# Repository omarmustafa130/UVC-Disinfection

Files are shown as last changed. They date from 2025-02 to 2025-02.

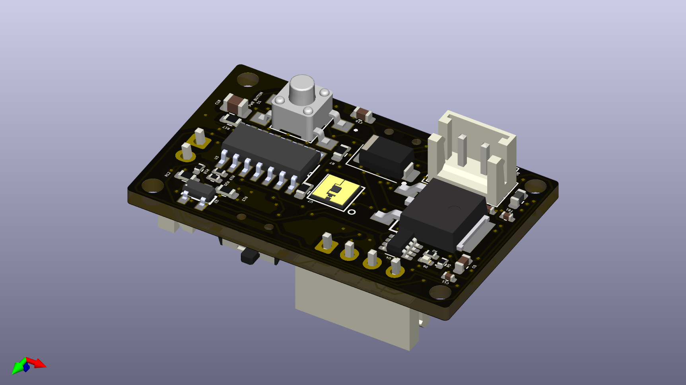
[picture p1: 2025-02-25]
Screenshots/Bottom3D_2.png

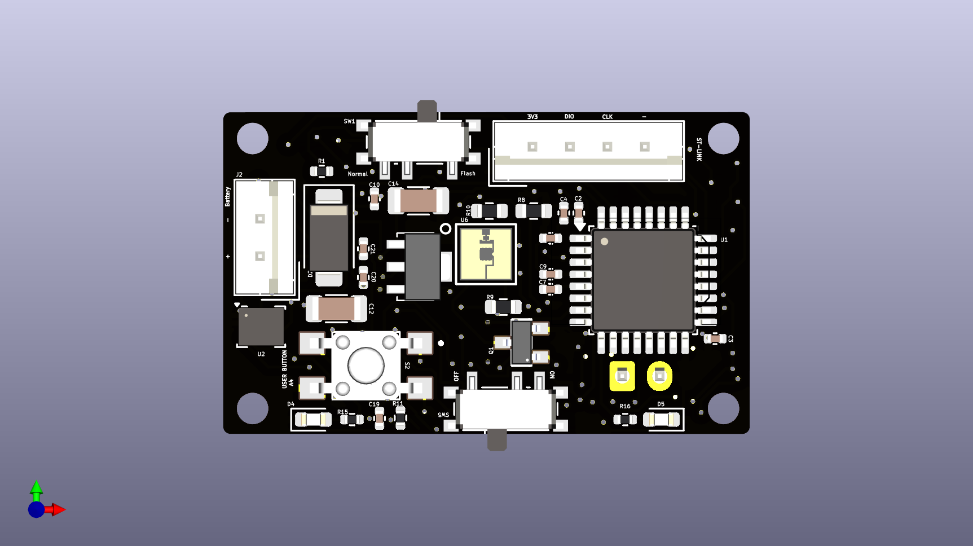
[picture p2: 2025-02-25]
Screenshots/Top3D_1.png

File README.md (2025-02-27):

# Hardware & PCB -- Scroll down for software part
The board is very, very compact, at just 21mm x 35mm, designed as a double-layer PCB, and integrates a smart power control system alongside motion-based UVC LED activation, and is able to last +30 days on battery.

The board features:
1- MCU: STM32L031K6T – a low-power Cortex-M0+ MCU to handle control logic efficiently.

2- Motion Sensing: LSM6DS3 – a 3D accelerometer & gyroscope determines orientation to activate the correct UVC LED.

3- UVC LEDs: 2x 254nm LEDs (23mW, 150mA) – ensure effective disinfection, switching every 60 minutes for 90 seconds based on orientation.

4- Power Management:
- L7BM06CDT (6V regulator)
- L78L33ACUTR (3.3V regulator) for the MCU
- MCP73831-2-MC (Li-ion charging IC) for battery management

5- User Interface & Control:
- Status LEDs (2x) & Power LED (1x) for feedback.
- A user button for additional interaction.
- Power Button using D Flip-Flop (74HC74) – holds power after a 5-second press, controlled via an RC delay circuit.
Instead of an always-on MCU (to save the battery), the device remains completely powered off until the user presses the power button for 5 seconds.
Uses a D flip-flop latch circuit with an RC network to ensure accidental presses don’t turn it on.
- ON/OFF Switch for direct power control when needed.
- 4-pin JST connector for ST-LINK interface
- Two 2-pin JST connector for the batteries and their charger

# Software 
# **STM32 UVC LED Control with Low Power Mode**

## **Overview**

This project controls **UVC LEDs** based on the device's **orientation**, using an **LSM6DS33 accelerometer**. It follows a power-efficient cycle:

1. **Waits 30 seconds** before activating.
2. **Blinks an indicator LED for 5 seconds**.
3. **Determines the orientation** of the device.
4. **Activates the appropriate UVC LED** for **90 seconds** while the indicator LED blinks.
5. **Turns OFF all LEDs** after operation.
6. **Enters deep sleep mode (STOP mode) for 1 hour** to conserve power.

The system **wakes up automatically after 1 hour** and repeats the cycle.

---

## **Hardware Requirements**

To test this code, you need:

- **STM32 (e.g., STM32F103RB Nucleo or similar)**
- **LSM6DS33 Accelerometer (I2C)**
- **UVC LEDs** (connected to GPIOA)
- **Indicator LEDs**
- **Power supply** (battery or USB)

---

## **Pin Configuration**

| **Component** | **GPIO Pin** | **Port** |
| --- | --- | --- |
| **Top UVC LED** | `GPIO_PIN_0` | `GPIOA`  |
| **Bottom UVC LED** | `GPIO_PIN_1` | `GPIOA`  |
| **Top Indicator LED** | `GPIO_PIN_3` | `GPIOA`  |
| **Bottom Indicator LED** | `GPIO_PIN_7` | `GPIOA`  |
| **I2C SDA** | `GPIO_PIN_9` | `GPIOB`  |
| **I2C SCL** | `GPIO_PIN_8` | `GPIOB`  |

---

## **Project Structure**

```
/STM32_UVC_LowPower/
│── Core/
│   ├── Inc/
│   │   ├── main.h
│   │   ├── LSM6DS33.h
│   ├── Src/
│   │   ├── main.c
│   │   ├── LSM6DS33.c
│── README.md
```

---

## **How It Works**

### **1- Initialization**

- **STM32 peripherals** (GPIO, I2C, System Clock) are initialized.
- **LSM6DS33 accelerometer** is configured.

### **2- LED Activation Sequence**

- **Waits 30 seconds** after boot.
- **Blinks indicator LED** for **5 seconds**.
- **Reads orientation** from **LSM6DS33**.
- **Turns ON the correct UVC LED** (based on orientation).
- **Blinks indicator LED for 90 seconds** while UVC LED is ON.
- **Turns OFF all LEDs** after the cycle.

### **3- Power Saving Mode**

- **Enters STOP mode (Deep Sleep) for 1 hour.**
- **Disables unused peripherals (GPIO, I2C) before sleep.**
- **Resumes peripherals after waking up.**
- **Restores system clock to normal operation.**
- **Repeats the process indefinitely.**

---

## **How to Test**

### **🔹 Option 1: Flash and Run**

1. **Flash the firmware** using STM32CubeProgrammer or an ST-Link.
2. **Connect serial monitor** to see debug messages (optional).
3. **Observe LED behavior**:
   - Indicator LED blinks for 5 seconds.
   - UVC LED turns ON based on orientation.
   - Indicator LED blinks for 90 seconds while UVC is ON.
   - After LEDs turn OFF, the system **enters low-power mode for 1 hour**.
   - The process repeats.

### **🔹 Option 2: Modify Sleep Duration for Testing**

Since **1-hour sleep is long**, modify `enter_low_power_mode()` for quicker tests:

```c
while ((HAL_GetTick() - tickstart) < 30000)  // 30 seconds instead of 1 hour
```

This allows testing the **wake-up cycle faster**.

---

## **Power Consumption & Optimization**

| **Mode** | **Power Consumption** |
| --- | --- |
| **Active (LEDs ON, CPU running)** | \~20mA |
| **Deep Sleep (STOP Mode, LEDs OFF)** | **\~200-500µA** |
| **Estimated Battery Life (1000mAh battery)** | \~66 Days |

🔹 **Further Power Optimizations:**

- Use **Standby Mode (\~1µA) instead of STOP mode**.
- **Disable more peripherals** (e.g., ADC, UART, timers).
- Use an **RTC wake-up instead of HAL\_GetTick().**

---

## **Troubleshooting**

### **1- STM32 Doesn’t Wake Up**

**Solution: Ensure SysTick timer is active**

- **HAL\_SuspendTick()** prevents unwanted wake-ups.
- **`SCB->SCR |= SCB_SCR_SLEEPDEEP_Msk;`** is required for STOP mode.

### **2- I2C Stops Working After Wake-up**

**Solution: Reset I2C after STOP mode**

```c
__HAL_RCC_I2C1_FORCE_RESET();
HAL_Delay(10);
__HAL_RCC_I2C1_RELEASE_RESET();
MX_I2C1_Init();
LSM6DS33_init();
```

### **3- UVC LED Doesn't Turn ON**

**Solution: Check orientation detection**

- Add debug prints:

```c
printf("Orientation: %d
", orientation);
```

---

## **Additional Resources**

- [STM32 HAL Documentation](https://www.st.com/en/embedded-software/stm32cube-mcu-packages.html)
- [LSM6DS33 Datasheet](https://www.st.com/resource/en/datasheet/lsm6ds33.pdf)
- [Low Power Modes on STM32](https://www.st.com/resource/en/application_note/an4830-lowpower-modes-for-stm32-mcus.pdf)

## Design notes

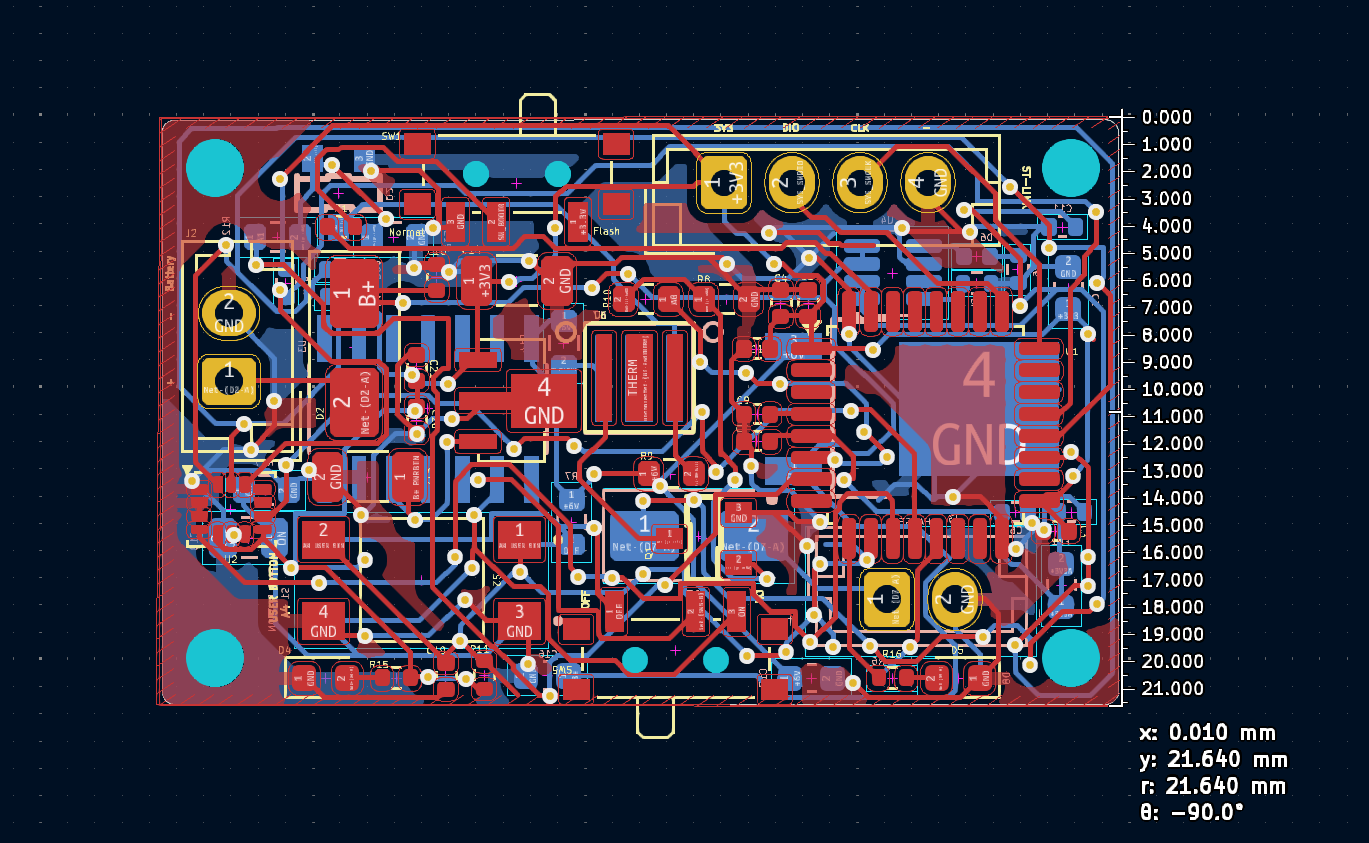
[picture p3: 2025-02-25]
Screenshots/dim2.png

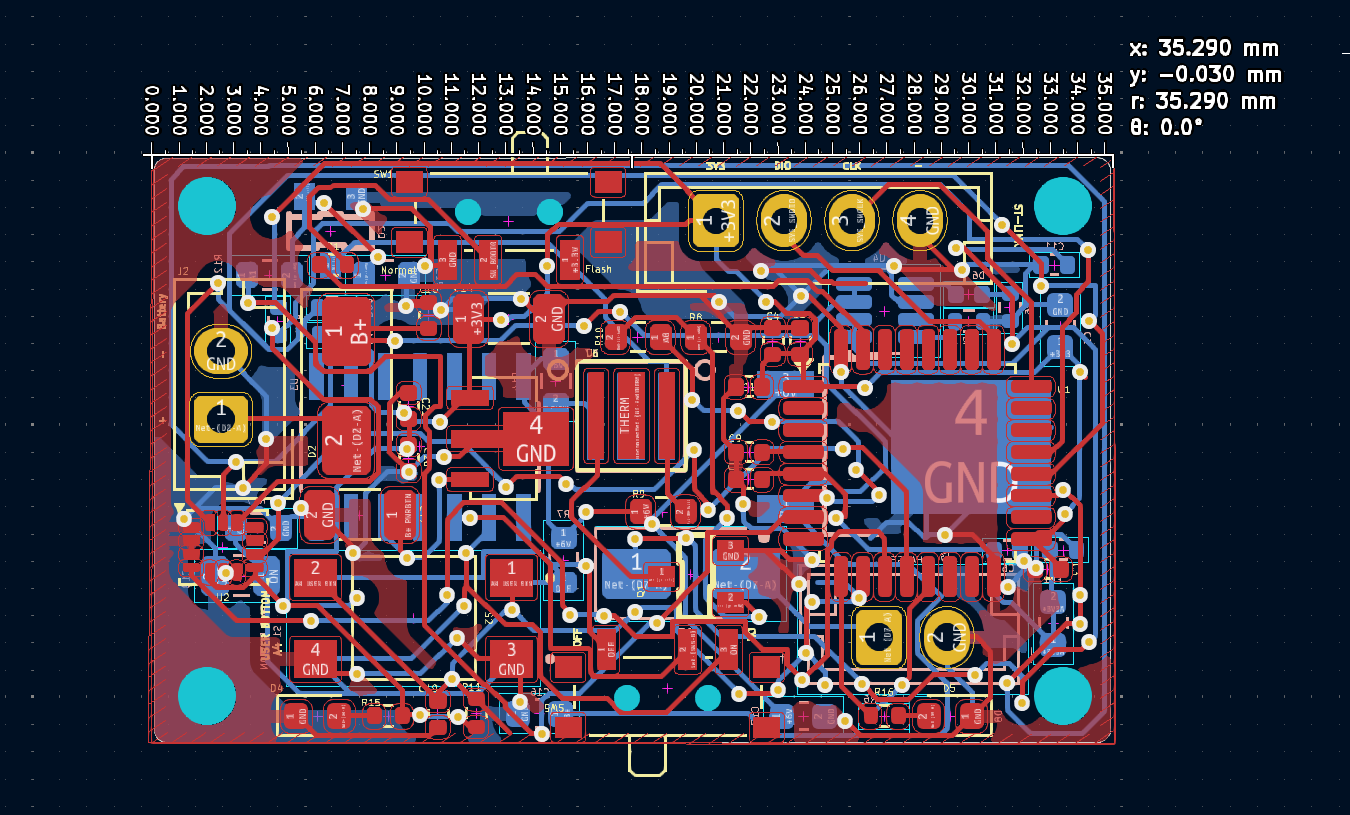
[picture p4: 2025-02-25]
Screenshots/dim1.png

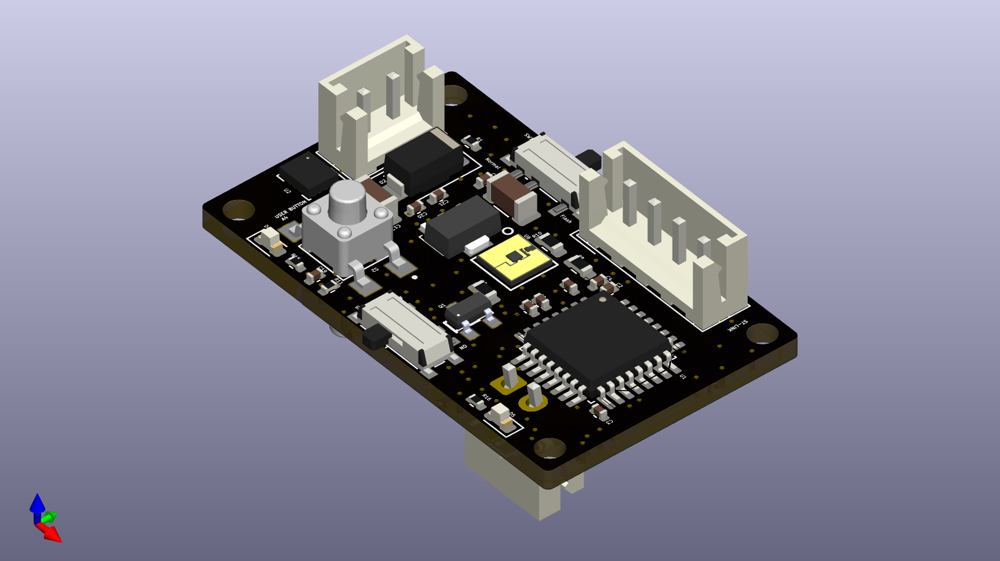
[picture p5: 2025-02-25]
Screenshots/Top3D_3.png

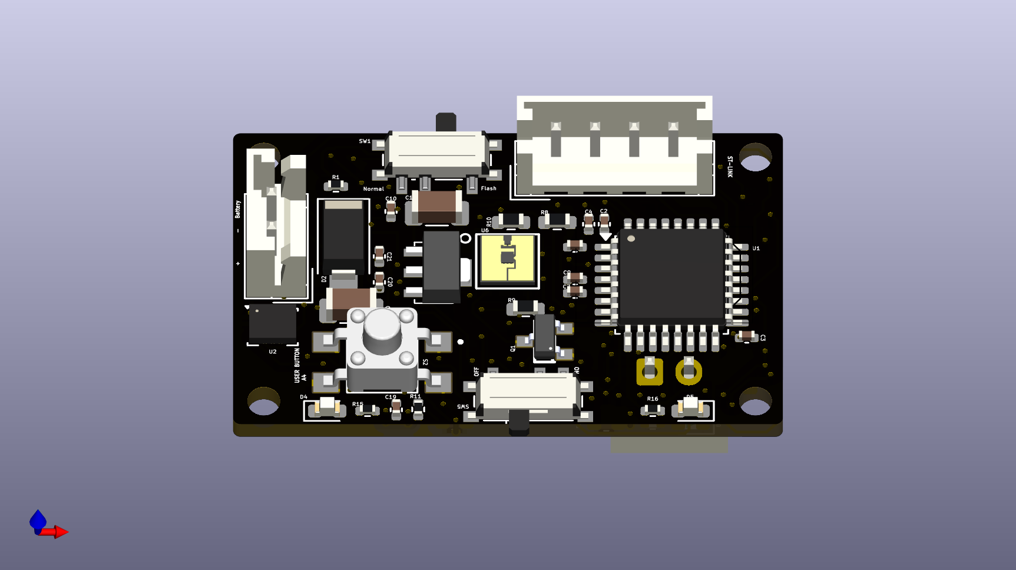
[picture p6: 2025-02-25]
Screenshots/Top3D_2.png

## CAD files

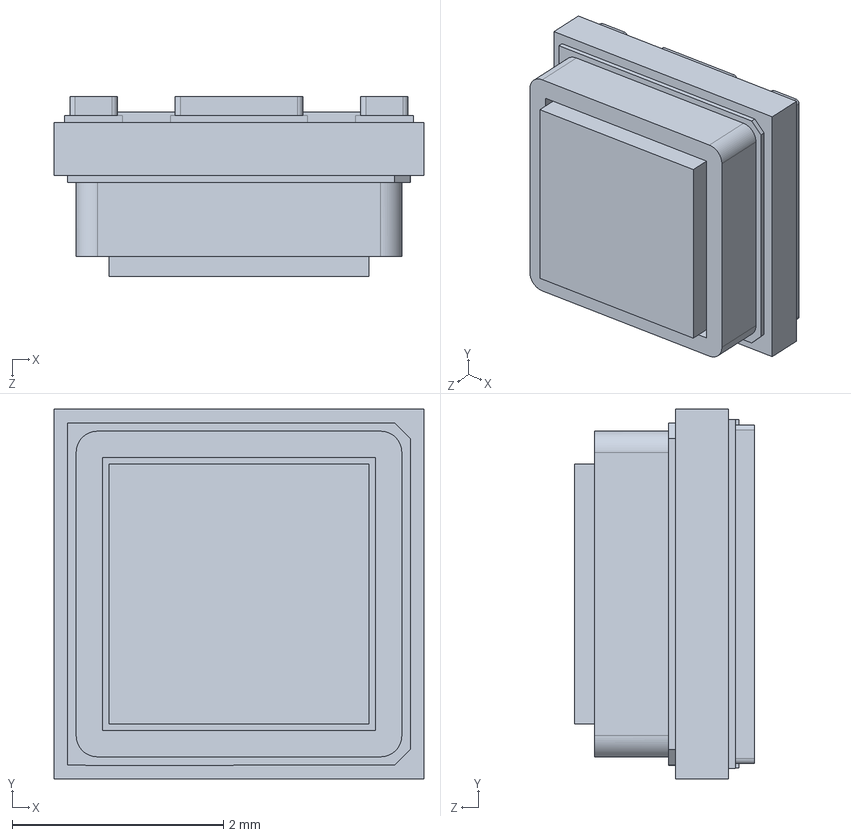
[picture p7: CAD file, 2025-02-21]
Additional symbols, footprints & 3D models/158810696-3-q65113a3141/SU_CULCN1_VC_20210621_geometry.STEP
3.50 x 3.50 x 1.70 mm

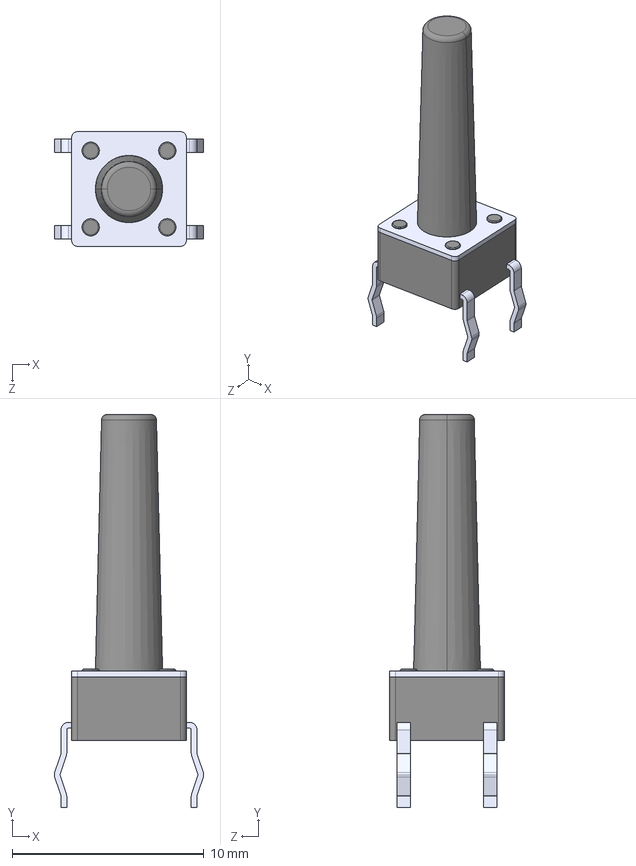
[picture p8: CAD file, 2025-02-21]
Additional symbols, footprints & 3D models/3-1825910-1/3-1825910-1.step
7.80 x 20.5 x 5.99 mm

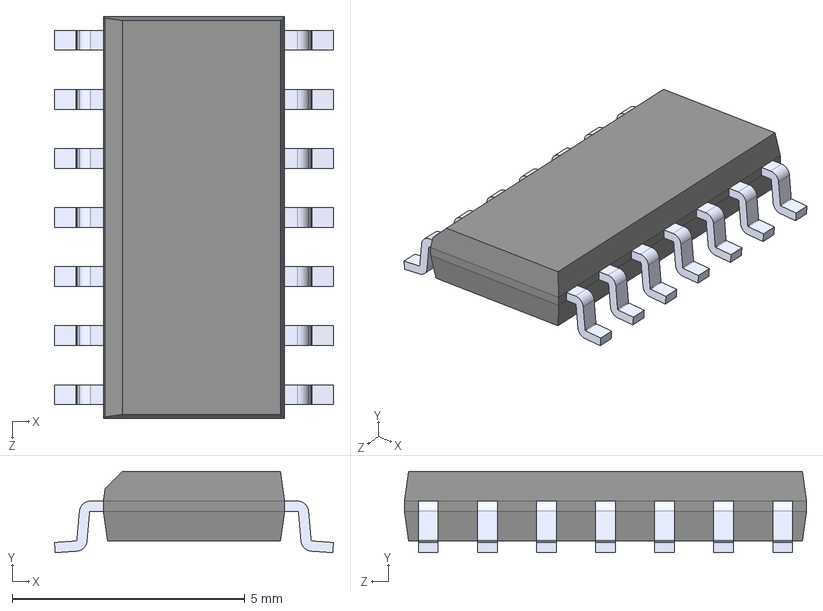
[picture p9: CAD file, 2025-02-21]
Additional symbols, footprints & 3D models/74HC74D_652/74HC74D_652.step
6.00 x 1.75 x 8.65 mm

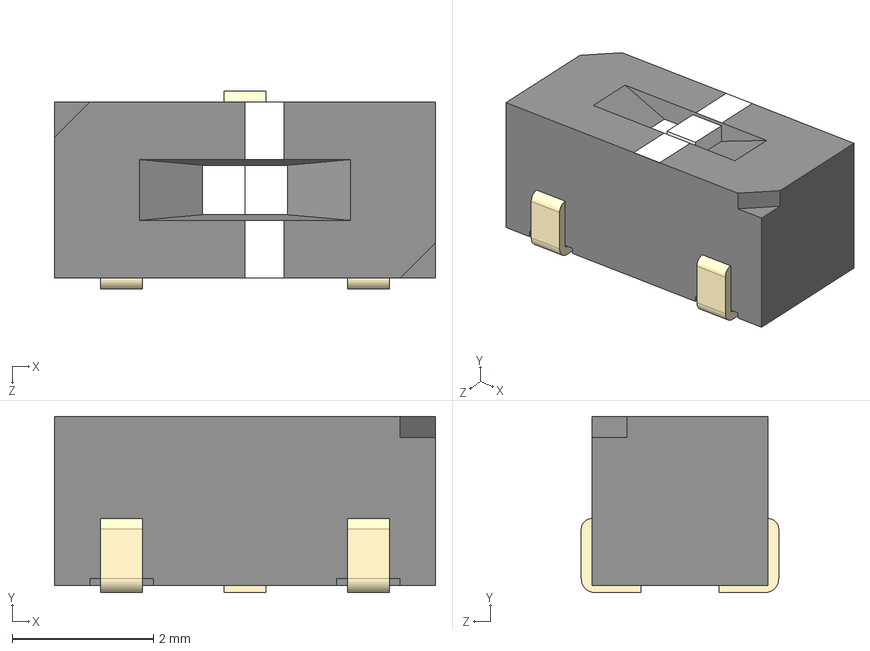
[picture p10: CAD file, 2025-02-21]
Additional symbols, footprints & 3D models/CJS-1200TA--3DModel-STEP-56544.STEP
5.40 x 2.50 x 2.80 mm

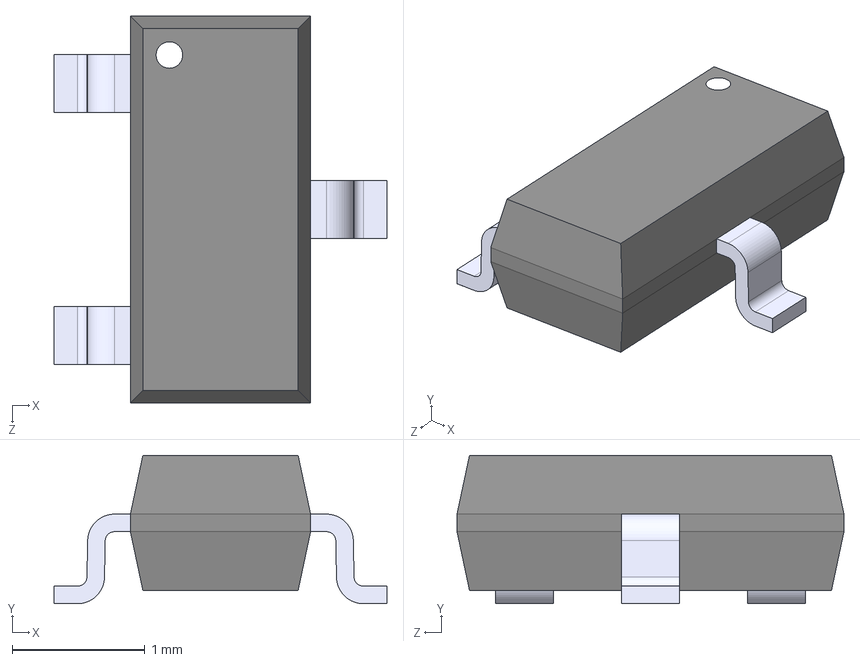
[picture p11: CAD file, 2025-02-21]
Additional symbols, footprints & 3D models/IRLML2402/IRLML2402.step
2.51 x 1.12 x 2.92 mm

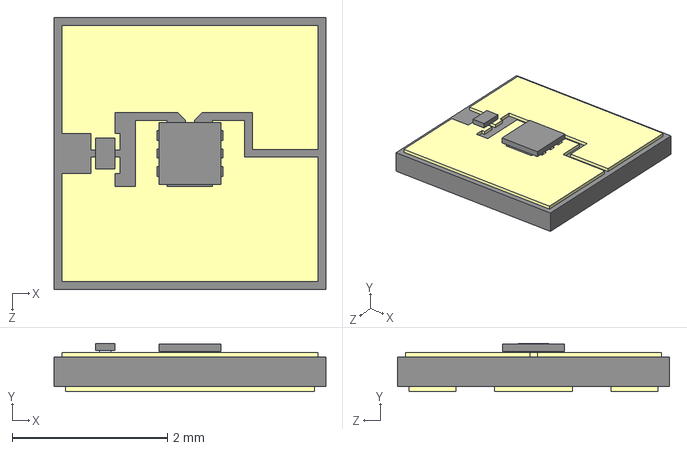
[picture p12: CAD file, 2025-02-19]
Additional symbols, footprints & 3D models/KL265-50U-SM-WD/KL265-50U-SM-WD.step
3.50 x 0.618 x 3.50 mm

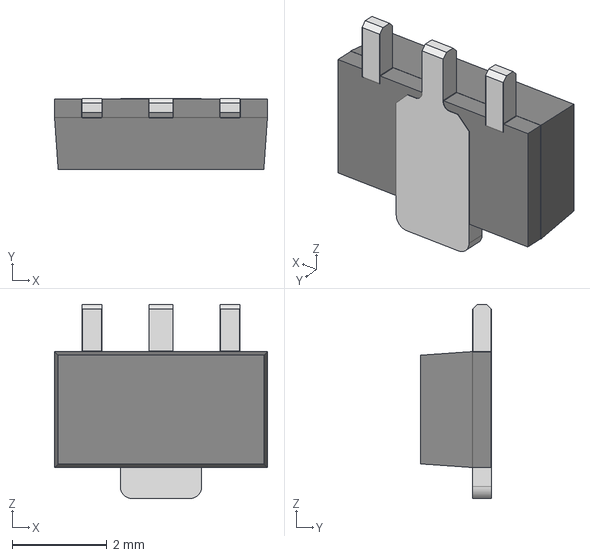
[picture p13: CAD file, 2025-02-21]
Additional symbols, footprints & 3D models/LIB_L78L33ACUTR/L78L33ACUTR/3D/L78L33ACUTR.stp
4.50 x 1.50 x 4.10 mm

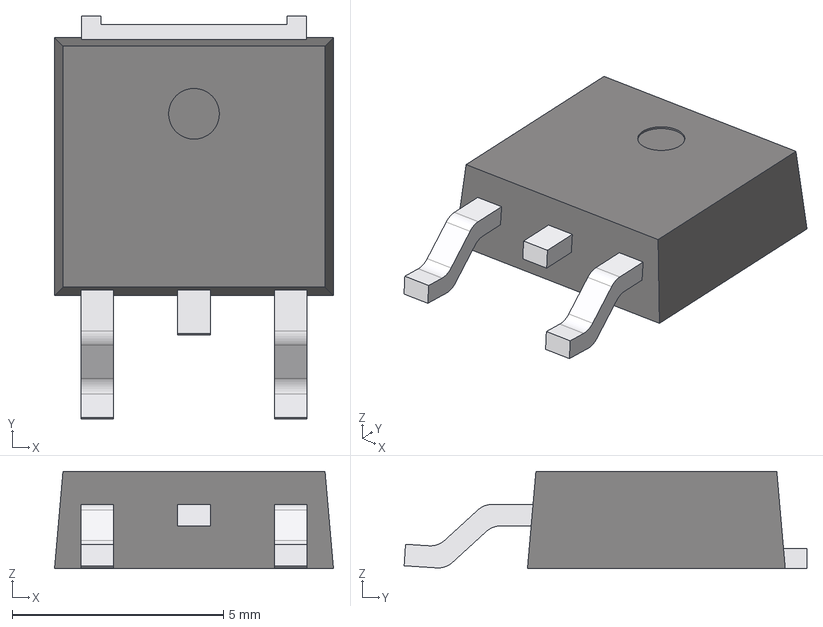
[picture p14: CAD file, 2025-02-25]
Additional symbols, footprints & 3D models/LIB_L78M06CDT-TR/L78M06CDT-TR/3D/L78M06CDT-TR.stp
6.60 x 9.53 x 2.30 mm

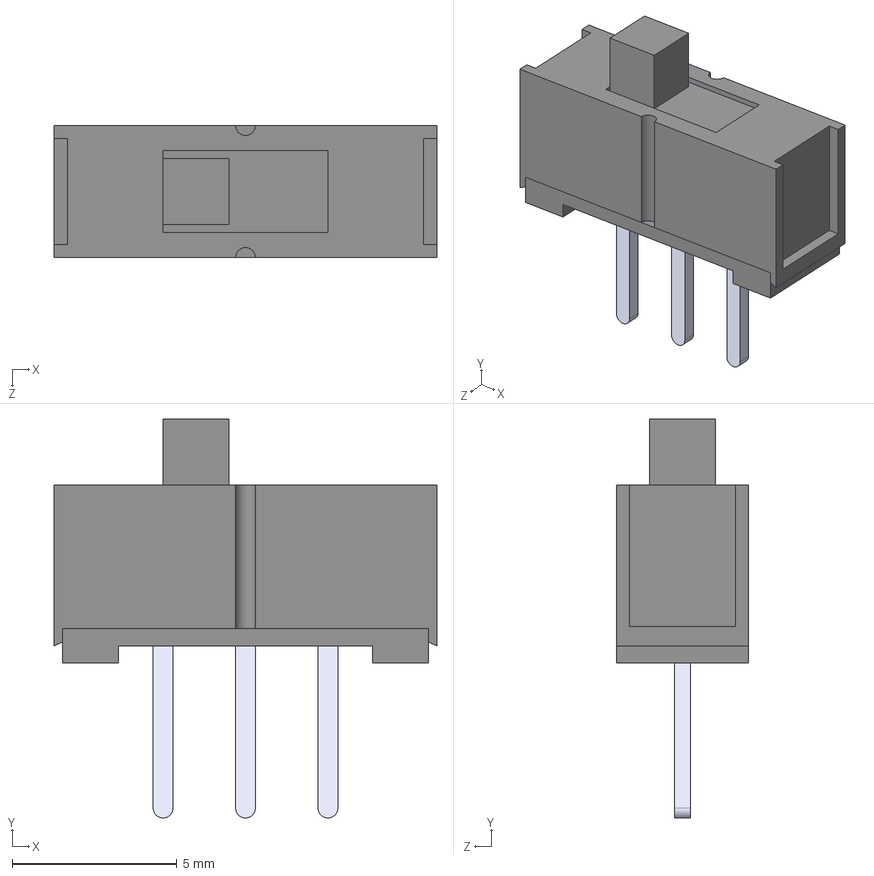
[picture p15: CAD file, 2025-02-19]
Additional symbols, footprints & 3D models/MINI-SPDT-SW/MINI-SPDT-SW.step
11.6 x 12.1 x 4.00 mm

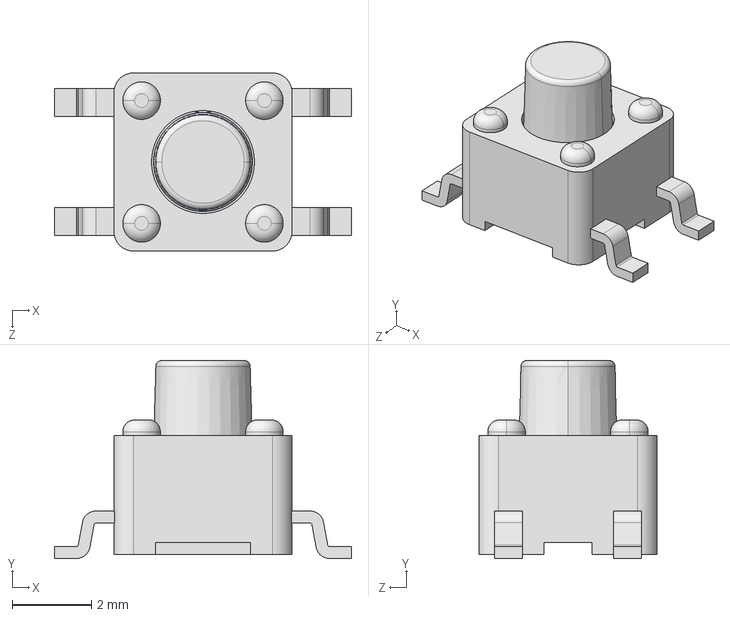
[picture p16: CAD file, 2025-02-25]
Additional symbols, footprints & 3D models/TL3305BF160QG/TL3305BF160QG.step
7.50 x 5.00 x 4.50 mm

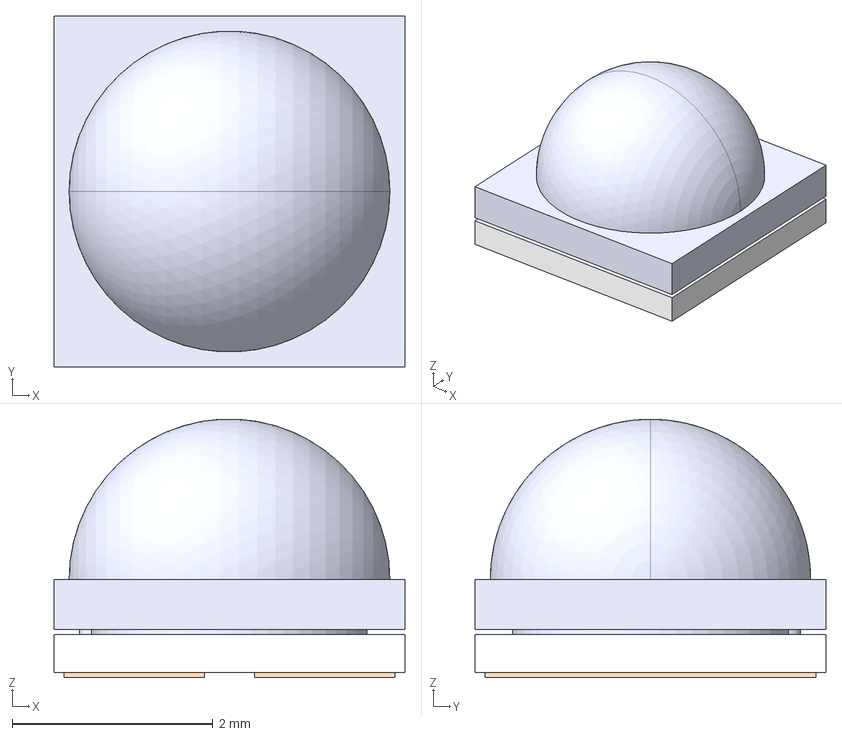
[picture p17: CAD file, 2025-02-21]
Additional symbols, footprints & 3D models/XST-3535-UV-A60-CE275-01--3DModel-STEP-483804.STEP
3.50 x 3.50 x 2.58 mm

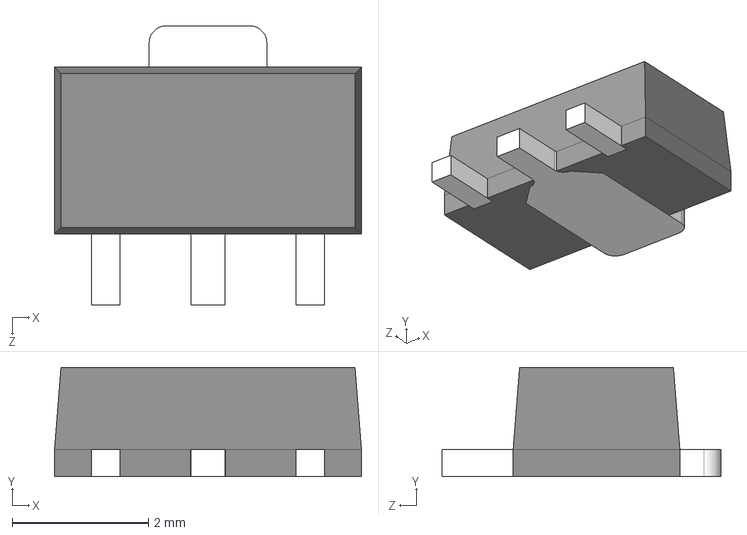
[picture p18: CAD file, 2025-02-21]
Additional symbols, footprints & 3D models/L78L33ACUTR.STEP
4.50 x 1.60 x 4.10 mm

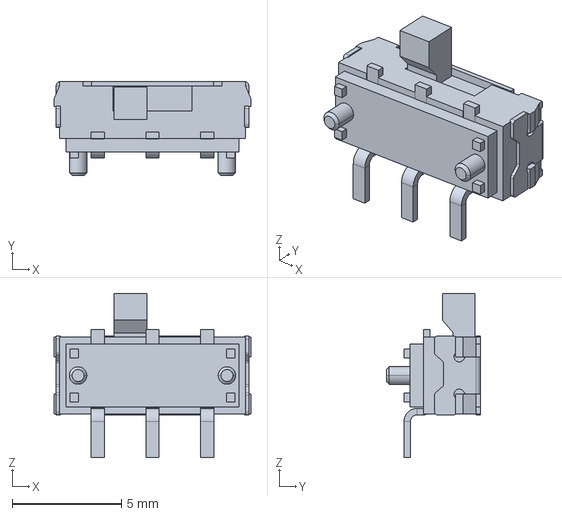
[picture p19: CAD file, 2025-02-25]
Additional symbols, footprints & 3D models/JS102011SAQN/JS102011SAQN.step
9.00 x 4.30 x 7.50 mm

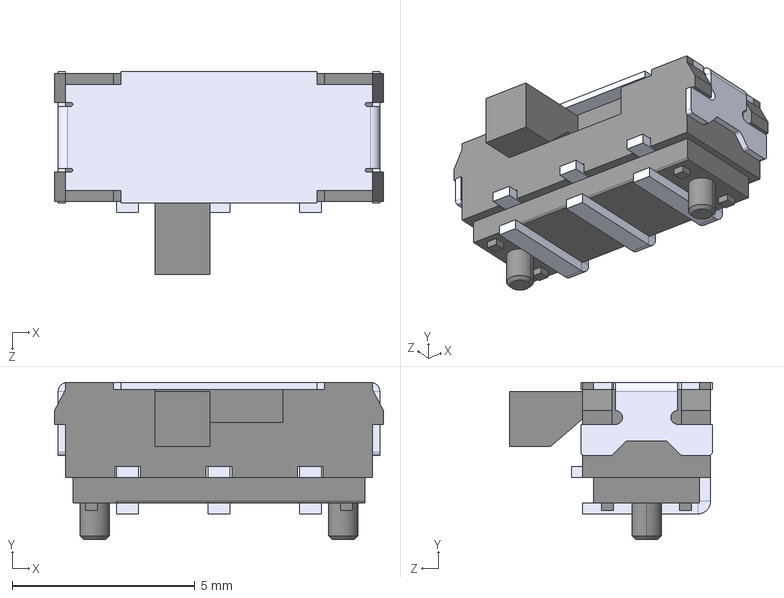
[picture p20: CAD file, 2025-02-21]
Additional symbols, footprints & 3D models/JS102011JAQN--3DModel-STEP-269445.STEP
9.00 x 4.30 x 5.55 mm

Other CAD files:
Additional symbols, footprints & 3D models/LIB_L78L33ACUTR/L78L33ACUTR/Allegro/ldk320adu30r.psm
Additional symbols, footprints & 3D models/LIB_L78L33ACUTR/L78L33ACUTR/DEHDL/l78l33acutr/chips/chips.prt
Additional symbols, footprints & 3D models/LIB_L78M06CDT-TR/L78M06CDT-TR/Allegro/to228p972x240-3n.psm
Additional symbols, footprints & 3D models/LIB_L78M06CDT-TR/L78M06CDT-TR/DEHDL/l78m06cdt_tr/chips/chips.prt
Additional symbols, footprints & 3D models/LIB_XC6190AC157R-G/XC6190AC157R-G/Allegro/xc6190ac157rg.psm
Additional symbols, footprints & 3D models/LIB_XC6190AC157R-G/XC6190AC157R-G/DEHDL/xc6190ac157r_g/chips/chips.prt

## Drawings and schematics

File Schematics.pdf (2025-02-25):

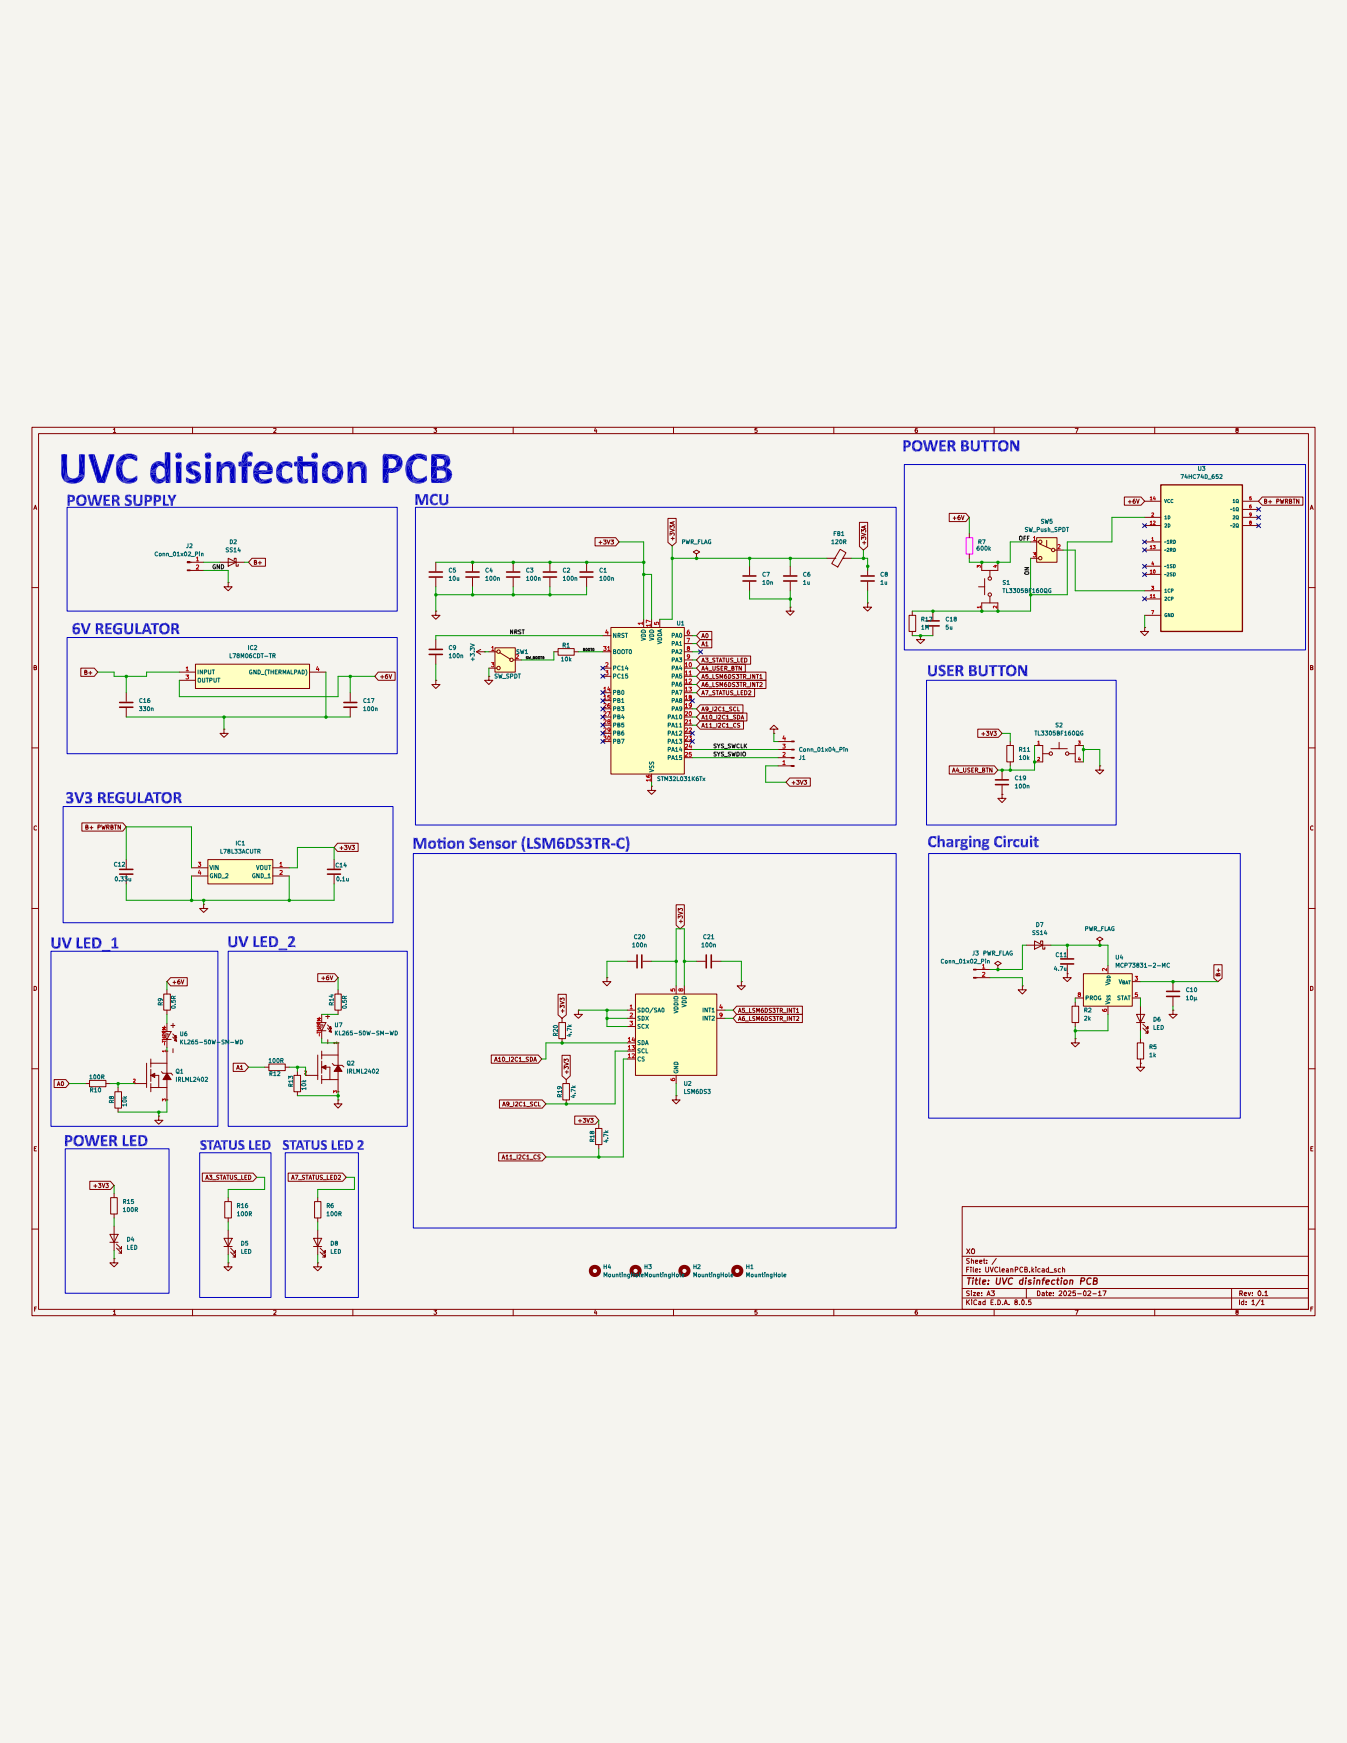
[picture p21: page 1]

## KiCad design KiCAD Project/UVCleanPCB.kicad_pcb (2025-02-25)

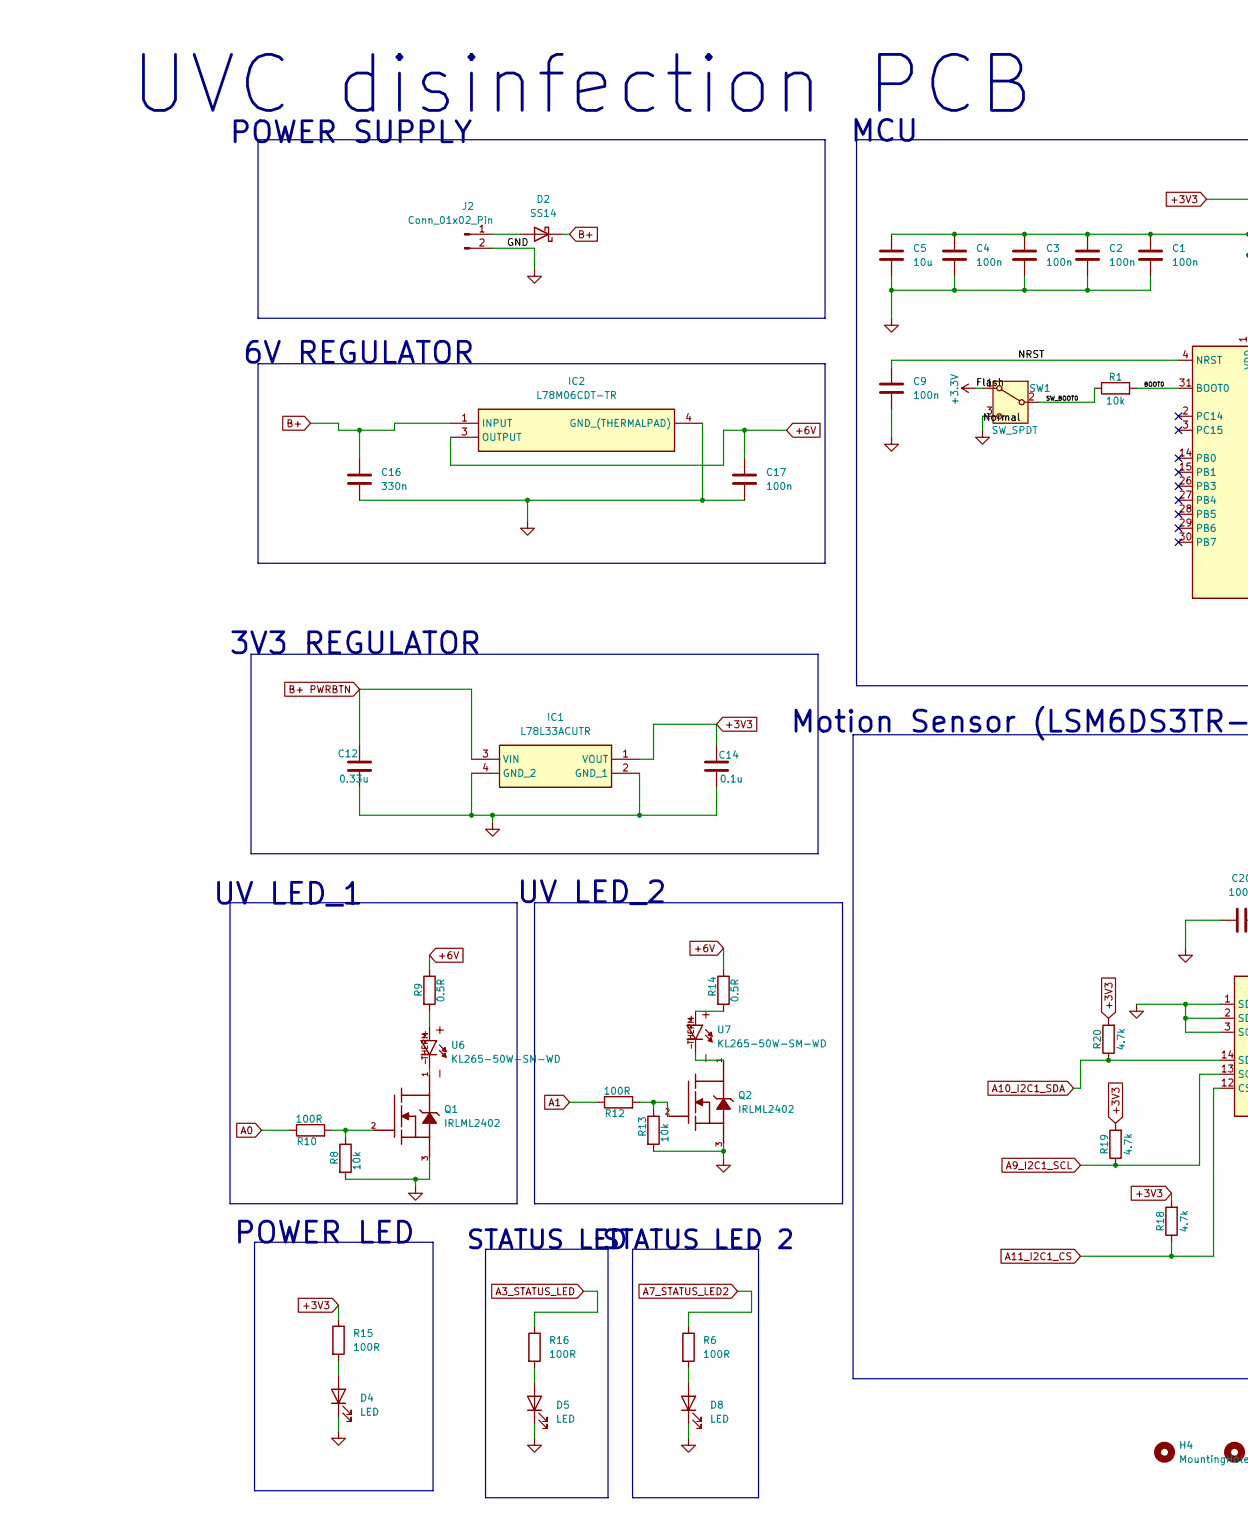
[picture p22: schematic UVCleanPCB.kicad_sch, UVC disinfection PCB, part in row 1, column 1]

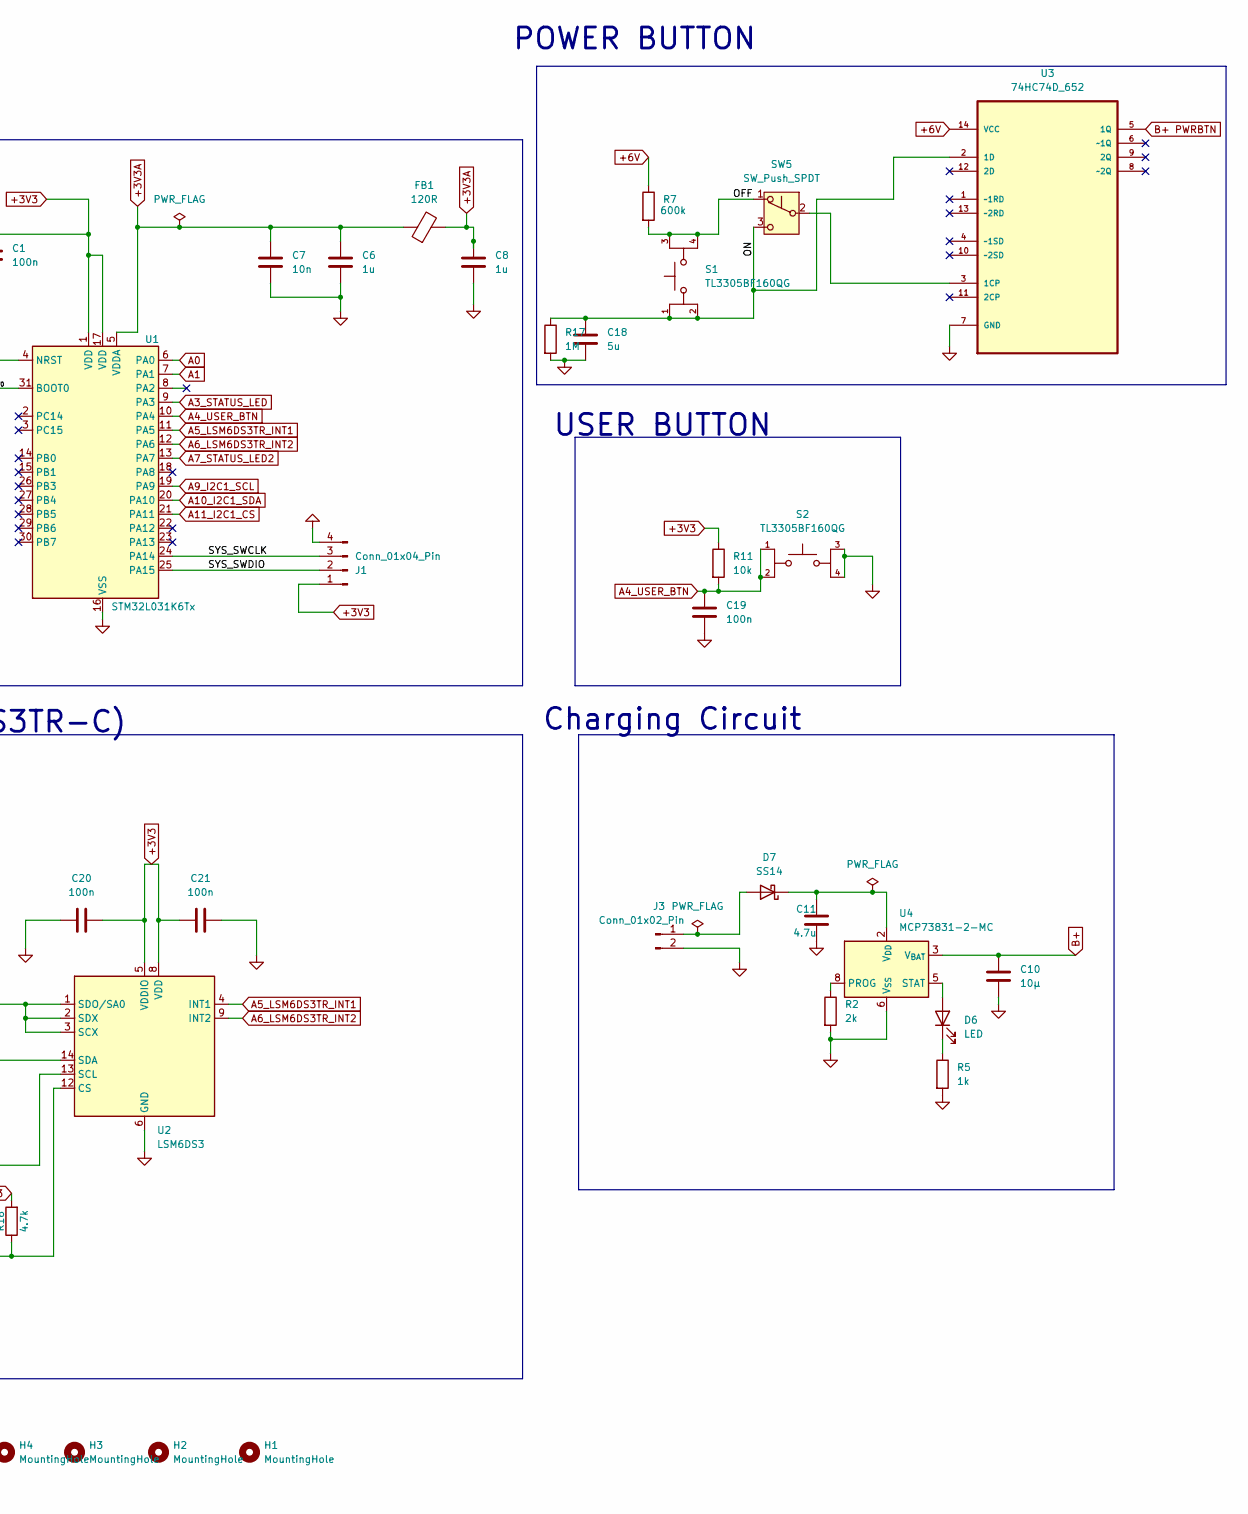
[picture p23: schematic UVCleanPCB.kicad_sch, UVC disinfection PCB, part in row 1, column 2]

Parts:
C1, C2, C3, C4, C9, C19, C20, C21: 100n; C_0402_1005Metric
C5: 10u; C_0603_1608Metric
C6, C8: 1u; C_0402_1005Metric
C7: 10n; C_0402_1005Metric
C10: 10µ; C_0402_1005Metric
C11: 4.7u; C_0402_1005Metric
C12: 0.33u; C_1206_3216Metric
C14: 0.1u; C_1206_3216Metric
C16: 330n; C_0603_1608Metric
C17: 100n; C_0603_1608Metric
C18: 5u; C_0805_2012Metric
D2, D7: SS14; D_SMA
D4, D5, D8: LED; LED_0603_1608Metric
D6: LED; LED_0402_1005Metric
FB1: 120R; L_0603_1608Metric
H1, H2, H3, H4: MountingHole; MountingHole_2.1mm
IC1: L78L33ACUTR; LDK320ADU30R; Mouser Part Number 511-L78L33ACU
IC2: L78M06CDT-TR; TO228P972X240-3N; Mouser Part Number 511-L78M06CDT-TR
J1: Conn_01x04_Pin; JST_EH_B4B-EH-A_1x04_P2.50mm_Vertical
J2, J3: Conn_01x02_Pin; JST_EH_B2B-EH-A_1x02_P2.50mm_Vertical
Q1, Q2: IRLML2402; SOT-23
R1, R11: 10k; R_0402_1005Metric
R2: 2k; R_0402_1005Metric
R5: 1k; R_0402_1005Metric
R6, R15, R16: 100R; R_0402_1005Metric
R7: 600k; R_0603_1608Metric
R8, R13: 10k; R_0603_1608Metric
R9, R14: 0.5R; R_0603_1608Metric
R10, R12: 100R; R_0603_1608Metric
R17: 1M; R_0603_1608Metric
R18, R19, R20: 4.7k; R_0402_1005Metric
S1, S2: TL3305BF160QG; SW_TL3305BF160QG; PARTREV C
SW1: SW_SPDT; SW_SPDT_PCM12
SW5: SW_Push_SPDT; SW_SPDT_PCM12
U1: STM32L031K6Tx; LQFP-32_7x7mm_P0.8mm
U2: LSM6DS3; LGA-14_3x2.5mm_P0.5mm_LayoutBorder3x4y
U3: 74HC74D_652; SOIC127P600X175-14N; MPN 74HC74D,652
U4: MCP73831-2-MC; SOT-23-8
U6, U7: KL265-50W-SM-WD; 3535

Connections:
+3.3V: SW1.1 (A)
+3V3: C1.1, C2.1, C3.1, C4.1, C5.1, C14.1, C20.2, C21.1, IC1.1 (VOUT), J1.1, R11.1, R15.1, R18.2, R19.2, R20.2, U1.1 (VDD), U1.17 (VDD), U2.5 (VDDIO), U2.8 (VDD)
+3V3A: C6.1, C7.1, C8.1, FB1.1, FB1.2, U1.5 (VDDA)
+6V: C17.1, IC2.3 (OUTPUT), R7.1, R9.1, R14.1, U3.14 (VCC)
/BOOT0: R1.2, U1.31 (BOOT0)
/NRST: C9.1, U1.4 (NRST)
/OFF: R7.2, S1.3, S1.4, SW5.1 (A)
/ON: C18.1, R17.1, S1.1, S1.2, SW5.3 (C), U3.2 (1D)
/SW_BOOT0: R1.1, SW1.2 (B)
/SYS_SWCLK: J1.3, U1.24 (PA14)
/SYS_SWDIO: J1.2, U1.25 (PA15)
A0: R10.1, U1.6 (PA0)
A1: R12.1, U1.7 (PA1)
A3_STATUS_LED: R16.1, U1.9 (PA3)
A4_USER_BTN: C19.1, R11.2, S2.1, S2.2, U1.10 (PA4)
A5_LSM6DS3TR_INT1: U1.11 (PA5), U2.4 (INT1)
A6_LSM6DS3TR_INT2: U1.12 (PA6), U2.9 (INT2)
A7_STATUS_LED2: R6.1, U1.13 (PA7)
A9_I2C1_SCL: R19.1, U1.19 (PA9), U2.13 (SCL)
A10_I2C1_SDA: R20.1, U1.20 (PA10), U2.14 (SDA)
A11_I2C1_CS: R18.1, U1.21 (PA11), U2.12 (CS)
B+: C10.1, C16.1, D2.1 (K), IC2.1 (INPUT), U4.3 (V_{BAT}), U4.4 (V_{BAT})
B+ PWRBTN: C12.1, IC1.3 (VIN), U3.5 (1Q)
GND: C1.2, C2.2, C3.2, C4.2, C5.2, C6.2, C7.2, C8.2, C9.2, C10.2, C11.2, C12.2, C14.2, C16.2, C17.2, C18.2, C19.2, C20.1, C21.2, D4.1 (K), D5.1 (K), D8.1 (K), IC1.2 (GND_1), IC1.4 (GND_2), IC2.4 (GND_(THERMALPAD)), J1.4, J2.2, J3.2, Q1.3, Q2.3, R2.2, R5.2, R8.2, R13.2, R17.2, S2.3, S2.4, SW1.3 (C), U1.16 (VSS), U1.32 (VSS), U2.1 (SDO/SA0), U2.2 (SDX), U2.3 (SCX), U2.6 (GND), U2.7 (GND), U3.7 (GND), U4.6 (V_{SS})
unnamed: D2.2 (A), J2.1
unnamed: D4.2 (A), R15.2
unnamed: D5.2 (A), R16.2
unnamed: D6.2 (A), U4.5 (STAT)
unnamed: D6.1 (K), R5.1
unnamed: D7.2 (A), J3.1
unnamed: C11.1, D7.1 (K), U4.1 (V_{DD}), U4.2 (V_{DD})
unnamed: D8.2 (A), R6.2
unnamed: Q1.1, U6.-
unnamed: Q1.2, R8.1, R10.2
unnamed: Q2.1, U7.-
unnamed: Q2.2, R12.2, R13.1
unnamed: R9.2, U6.+
unnamed: R14.2, U7.+
unnamed: SW5.2 (B), U3.3 (1CP)
unnamed: R2.1, U4.8 (PROG)

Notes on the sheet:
POWER LED
MCU
UV LED_1
UV LED_2
POWER SUPPLY
6V REGULATOR
USER BUTTON
POWER BUTTON
Charging Circuit
3V3 REGULATOR
Motion Sensor (LSM6DS3TR-C)
STATUS LED 2
UVC disinfection PCB
STATUS LED

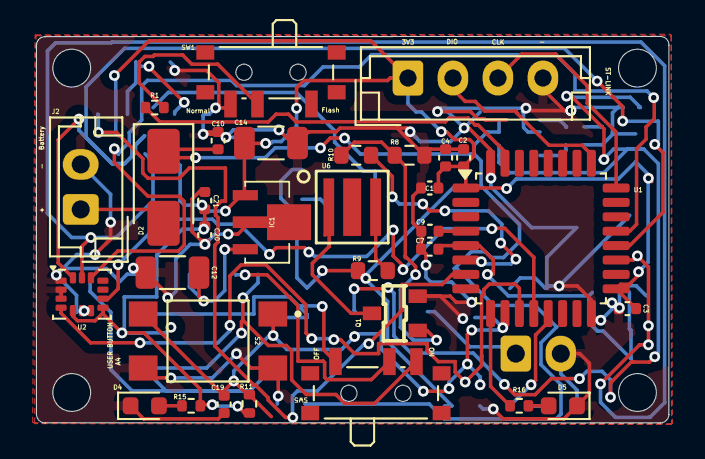
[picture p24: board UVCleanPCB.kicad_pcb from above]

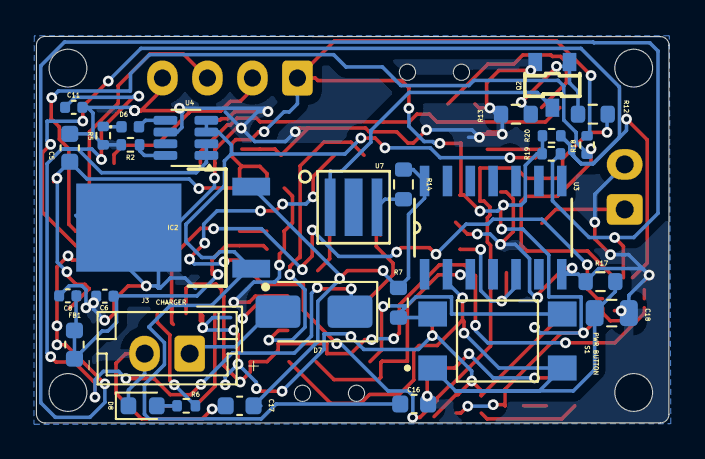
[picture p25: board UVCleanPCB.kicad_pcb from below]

Board: 2 copper layers, 35.1 x 21.5 mm, 65 parts (29 on the bottom side), 39 nets.

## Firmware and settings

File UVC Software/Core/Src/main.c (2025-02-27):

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
/* Includes ------------------------------------------------------------------*/
#include "main.h"

/* USER CODE BEGIN Includes */
#include "LSM6DS33.h"
/* USER CODE END Includes */

/* USER CODE BEGIN PTD */
// Global or static for orientation
typedef enum {
    TOP_SIDE_UP,
    BOTTOM_SIDE_UP
} OrientationType;
/* USER CODE END PTD */

/* USER CODE BEGIN PD */
// Define GPIO Ports & Pins
#define TOP_UVC_LED_Pin       		GPIO_PIN_0
#define TOP_UVC_LED_GPIO_Port 		GPIOA

#define BOTTOM_UVC_LED_Pin       	GPIO_PIN_1
#define BOTTOM_UVC_LED_GPIO_Port 	GPIOA

#define TOP_INDICATOR_LED_Pin       GPIO_PIN_3
#define BOTTOM_INDICATOR_LED_Pin    GPIO_PIN_7

#define INDICATOR_LED_GPIO_Port 	GPIOA
/* USER CODE END PD */

I2C_HandleTypeDef hi2c1;


/* USER CODE BEGIN PV */
int indicatorBlinking = 0;

/* USER CODE END PV */

void SystemClock_Config(void);
static void MX_GPIO_Init(void);
static void MX_I2C1_Init(void);
/* USER CODE BEGIN PFP */
/* USER CODE BEGIN PFP */
OrientationType get_orientation(void);
void start_indicator_blink(void);
void stop_indicator_blink(void);
void enter_low_power_mode(void);
/* USER CODE END PFP */

/**
  * @brief  The application entry point.
  * @retval int
  */
int main(void)
{

  /* MCU Configuration--------------------------------------------------------*/

  /* Reset of all peripherals, Initializes the Flash interface and the Systick. */
  HAL_Init();

  /* Configure the system clock */
  SystemClock_Config();

  /* Initialize all configured peripherals */
  MX_GPIO_Init();
  MX_I2C1_Init();
  /* USER CODE BEGIN 2 */
  // Initialize the sensor
  LSM6DS33_init();
  /* USER CODE END 2 */

  /* Infinite loop */
  /* USER CODE BEGIN WHILE */
  while (1)
  {
    /* USER CODE END WHILE */
	// --- PHASE 1: Wait 30 seconds ---
	HAL_Delay(25000);

	// Start blinking indicator LED for 5 seconds before UVC turns ON
	start_indicator_blink();

	// --- PHASE 2: Determine orientation ---
	OrientationType orientation = get_orientation();

	// --- PHASE 3: Turn ON the correct UVC LED ---
	if (orientation == TOP_SIDE_UP)
	{
		HAL_GPIO_WritePin(TOP_UVC_LED_GPIO_Port, TOP_UVC_LED_Pin, GPIO_PIN_SET);
	}
	else
	{
		HAL_GPIO_WritePin(BOTTOM_UVC_LED_GPIO_Port, BOTTOM_UVC_LED_Pin, GPIO_PIN_SET);
	}
    HAL_GPIO_WritePin(INDICATOR_LED_GPIO_Port, TOP_INDICATOR_LED_Pin, GPIO_PIN_RESET);
    HAL_GPIO_WritePin(INDICATOR_LED_GPIO_Port, BOTTOM_INDICATOR_LED_Pin, GPIO_PIN_RESET);
	// --- PHASE 4: Keep Indicator LED blinking WHILE UVC is ON (90 seconds) ---
	if (orientation == TOP_SIDE_UP)
	{

		for (int i = 0; i < 180; i++)  // 90s / 500ms = 180 blinks
		{
			HAL_GPIO_TogglePin(INDICATOR_LED_GPIO_Port, TOP_INDICATOR_LED_Pin);
			HAL_Delay(500);  // 500ms blink interval
		}
	}
	else
	{
		for (int i = 0; i < 180; i++)  // 90s / 500ms = 180 blinks
		{
			HAL_GPIO_TogglePin(INDICATOR_LED_GPIO_Port, BOTTOM_INDICATOR_LED_Pin);
			HAL_Delay(500);  // 500ms blink interval
		}
	}
	// --- PHASE 5: Turn off both UVC LEDs ---
	HAL_GPIO_WritePin(TOP_UVC_LED_GPIO_Port, TOP_UVC_LED_Pin, GPIO_PIN_RESET);
	HAL_GPIO_WritePin(BOTTOM_UVC_LED_GPIO_Port, BOTTOM_UVC_LED_Pin, GPIO_PIN_RESET);

	// --- PHASE 6: Stop Indicator LED ---
	stop_indicator_blink();

	// --- PHASE 7: Enter Low-Power Mode for 1 Hour ---
	enter_low_power_mode();
    /* USER CODE BEGIN 3 */
  }
  /* USER CODE END 3 */
}

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
/* USER CODE BEGIN 4 */
OrientationType get_orientation(void)
{
    float ax = read_data_acc(1);  // ✅ Correct
    float ay = read_data_acc(2);
    float az = read_data_acc(3);

    float absX = fabs(ax);
    float absY = fabs(ay);
    float absZ = fabs(az);

    // Determine which side is up
    if (absZ >= absX && absZ >= absY)
    {
        if (az > 0.5) return TOP_SIDE_UP;  // Slight tilt tolerance
        else if (az < -0.5) return BOTTOM_SIDE_UP;
    }

    // If it's on its side, decide based on tilt
    return (az >= 0) ? TOP_SIDE_UP : BOTTOM_SIDE_UP;
}

void enter_low_power_mode(void)
{
    uint32_t tickstart = HAL_GetTick();

    // ✅ Disable Unused Peripherals Before Sleep
    __HAL_RCC_GPIOA_CLK_DISABLE();
    __HAL_RCC_GPIOB_CLK_DISABLE();
    __HAL_RCC_I2C1_CLK_DISABLE();

    // ✅ Suspend SysTick to prevent unwanted wake-ups
    HAL_SuspendTick();

    // ✅ Set SLEEPDEEP only once before entering sleep loop
    SCB->SCR |= SCB_SCR_SLEEPDEEP_Msk;

    while ((HAL_GetTick() - tickstart) < 3600000)  // 1 Hour = 3,600,000 ms
    {
        __WFI();  // ✅ Enter STOP Mode (Deep Sleep)
    }

    // ✅ MCU Wakes Up Here

    // ✅ Restore System Clock (STOP mode disables HSI)
    SystemClock_Config();

    // ✅ Resume SysTick After Wake-up
    HAL_ResumeTick();

    // ✅ Re-enable Peripherals After Wake-up
    __HAL_RCC_GPIOA_CLK_ENABLE();
    __HAL_RCC_GPIOB_CLK_ENABLE();
    __HAL_RCC_I2C1_CLK_ENABLE();

    // ✅ Reset I2C & Reinitialize Accelerometer
    __HAL_RCC_I2C1_FORCE_RESET();
    HAL_Delay(10);
    __HAL_RCC_I2C1_RELEASE_RESET();
    MX_I2C1_Init();
    LSM6DS33_init();
}


void start_indicator_blink(void)
{
    // Blink the indicator LED 10 times for full 5 seconds
    for (int i = 0; i < 10; i++)
    {
        HAL_GPIO_TogglePin(INDICATOR_LED_GPIO_Port, TOP_INDICATOR_LED_Pin);
        HAL_GPIO_TogglePin(INDICATOR_LED_GPIO_Port, BOTTOM_INDICATOR_LED_Pin);
        HAL_Delay(500);  // 500ms blink interval
    }
}



void stop_indicator_blink(void)
{
    // Ensure LED is off
    HAL_GPIO_WritePin(INDICATOR_LED_GPIO_Port, TOP_INDICATOR_LED_Pin, GPIO_PIN_RESET);
    HAL_GPIO_WritePin(INDICATOR_LED_GPIO_Port, BOTTOM_INDICATOR_LED_Pin, GPIO_PIN_RESET);

}

/* USER CODE END 4 */
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


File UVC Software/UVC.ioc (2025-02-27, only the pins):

Mcu.UserName=STM32L031K6Tx
PA10.Signal=I2C1_SDA
PA9.Signal=I2C1_SCL

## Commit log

2025-02-18 Schematics V0.1
    [UVCleanPCB.kicad_pcb, UVCleanPCB.kicad_sch]
2025-02-18 Schematics V0.1 PDF
2025-02-19 Additional symbols and footprints
    [KL265-50W-SM-WD.step, MINI-SPDT-SW.step, UVCleanPCB.kicad_pcb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]
2025-02-19 6.5V regulator
2025-02-21 Additional footprints
    [3-1825910-1.step, 74HC74D,652.STEP, 74HC74D_652.step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]
2025-02-21 Final schematics
2025-02-21 PCB layout
    [UVCleanPCB.kicad_pcb]
2025-02-25 Project finalized
    [3-1825910-1.step, 74HC74D,652.STEP, 74HC74D_652.step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]

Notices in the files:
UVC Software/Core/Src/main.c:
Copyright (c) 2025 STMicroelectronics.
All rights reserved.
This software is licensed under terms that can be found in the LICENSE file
